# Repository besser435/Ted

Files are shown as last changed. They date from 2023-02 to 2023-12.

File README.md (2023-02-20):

# Ted
This is to store all of my Voron V0 3D printer stuff, including automated backups using the KIAUH gcode shell extention, and some other stuff like firmware and slicer profiles.
One important thing to note is that the autocommit script doesn't track deletions. 

To backup config files manually (run with `bash` NOT `sh`:
```
cd ~/Ted
bash autocommit.sh

```

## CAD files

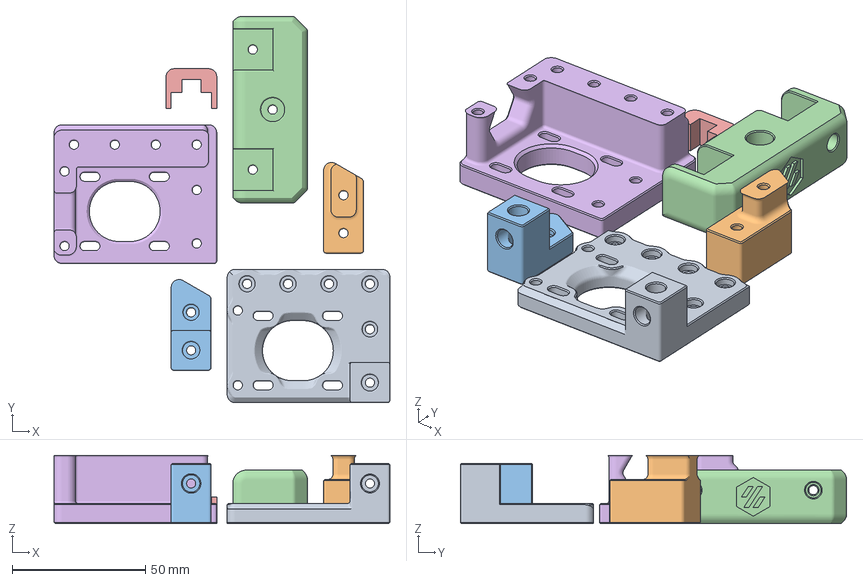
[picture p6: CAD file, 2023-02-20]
VORON Print Files/Main Parts/Batch 1 Main Parts/Batch 1 Main Parts.3mf
125.9 x 144.8 x 25.5 mm
B_Drive_Frame_Top_x1.STL
B_Idler_Bottom_x1.STL
B_Idler_Top_x1.STL
Front_Bed_Mount_x1.STL
MGN7_Rail_Guide_x2.STL
B_Drive_Frame_Bottom_x1.STL

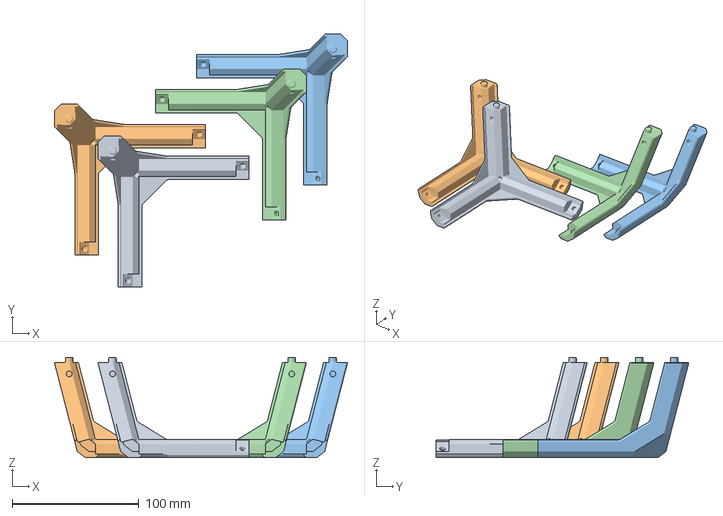
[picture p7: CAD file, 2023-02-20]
VORON Print Files/Tophat/Tophat Main Parts.3mf
231.1 x 199.1 x 79.0 mm
TopHat_Right_x2.STL
TopHat_Left_x2.stl

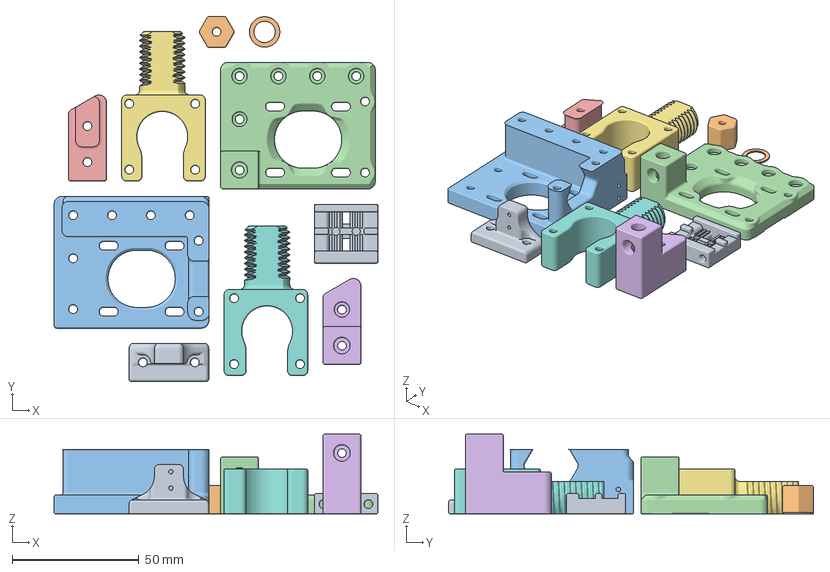
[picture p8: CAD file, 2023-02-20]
VORON Print Files/Main Parts/Batch 1 Main Parts/Accent Batch 1 Main Parts/Accent Batch 1 Main Parts.3mf
127.6 x 144.0 x 31.5 mm
[a]_Z_Endstop_Mount_x1.STL
[a]_Z_Leadscrew_Spacer_x1.stl
A_Drive_Frame_Bottom_x1.STL
A_Drive_Frame_Top_x1.STL
A_Idler_Bottom_x1.STL
A_Idler_Top_x1.STL
[a]_A_Drive_Tensioner_x1.STL
[a]_B_Drive_Tensioner_x1.STL
[a]_Belt_Retension_Block_x1.stl
[a]_Endstop_Strike_Block_x1.STL

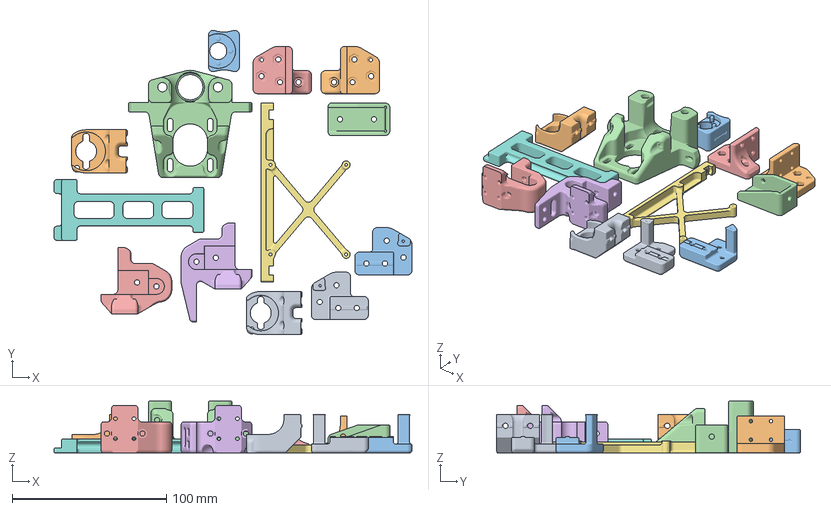
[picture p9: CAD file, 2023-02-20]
VORON Print Files/Main Parts/Batch 2 Main Parts/Batch 2 Main Parts.3mf
231.9 x 197.1 x 33.5 mm
XY_Joint_Left_Top_x1.STL
XY_Joint_Right_Bottom_x1.STL
XY_Joint_Right_Top_x1.STL
Z_Motor_Mount_x1.STL
Rear_Bed_Mount_Left_x1.STL
Rear_Bed_Mount_Right_x1.STL
RPi_Frame_x1.stl
Spool_Holder_V0_x1.STL
T8_Nut_Block_16mmx22mmOD_x1.STL
T8_Nut_Block_18mmx24mmOD_x1.STL
T-Nut_Mod_Tool_x1.STL
V0_Extrusion_Drilling_Guide_x1.STL
XY_Joint_Left_Bottom_x1.STL

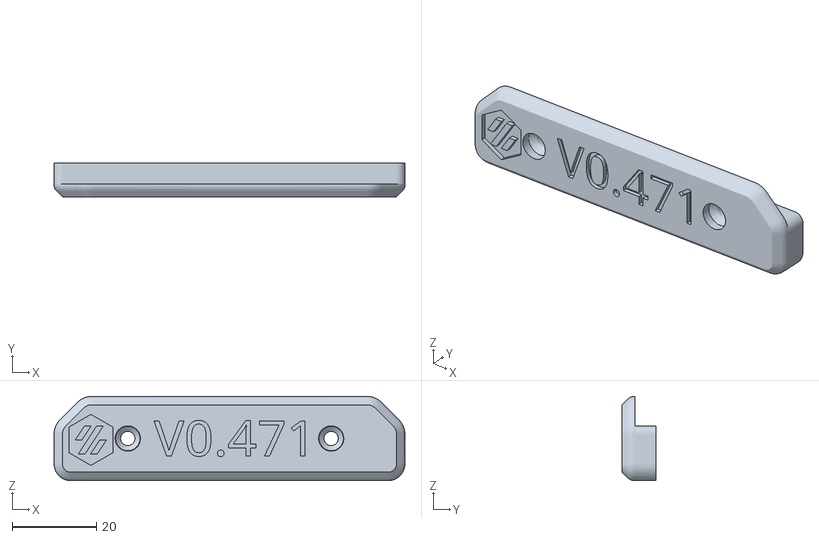
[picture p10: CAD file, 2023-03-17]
V0 SN.stl
83.2 x 8.00 x 20.0

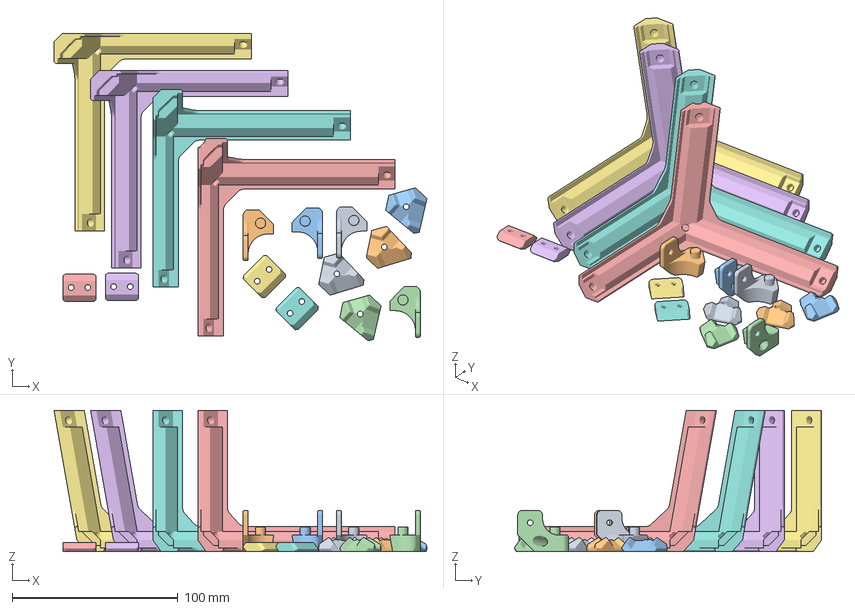
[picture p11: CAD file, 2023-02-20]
VORON Print Files/Bunged Up Files (Made for v0.1)/Enclosure (Contains Multiples)/(B) Entire Enclosure PLAquestionmark.3mf
224.8 x 185.1 x 85.0 mm
Lower_Corner_1_and_3_Clip_x2.stl
Lower_Corner_2_and_4_Clip_x2.STL
Tophat_Part1_x1.STL
Tophat_Part2_x2.STL
Tophat_Part3_x1.STL
Upper_Corner_1_and_3_Clip_x2.STL
Upper_Corner_2_and_4_Clip_x2.STL
Front_and_Rear_Midclip_x2.STL
Left_and_Right_Midclip_x2.STL

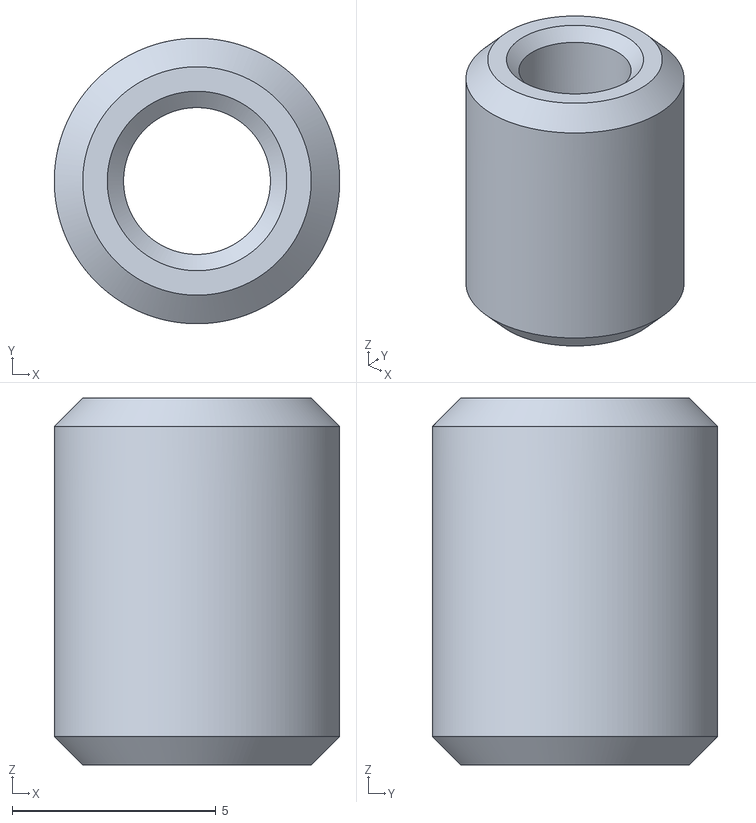
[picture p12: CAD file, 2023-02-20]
VORON Print Files/Bunged Up Files (Made for v0.1)/Mulitples of parts/[a]_9mm_Spacer_x6.stl
7.00 x 7.00 x 9.00

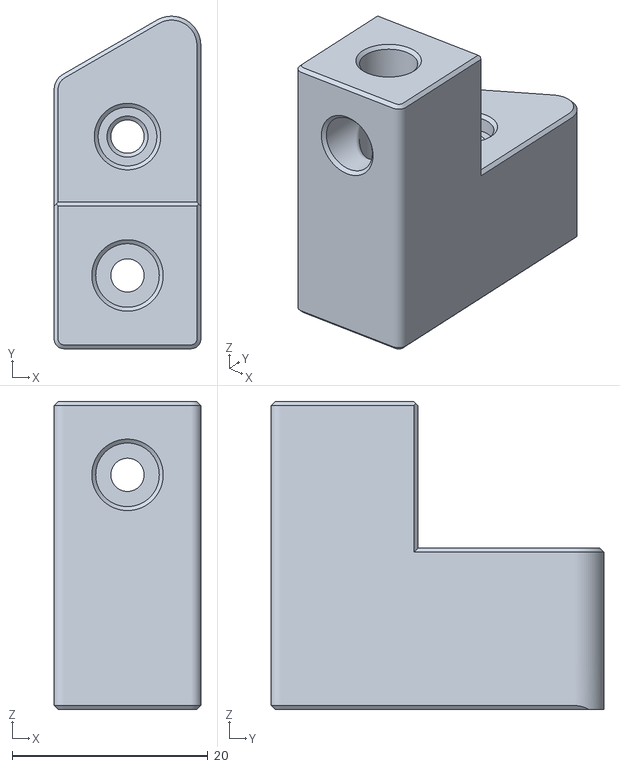
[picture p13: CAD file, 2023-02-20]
VORON Print Files/Bunged Up Files (Made for v0.1)/Regular Parts/Batch 1/Accent/A_Idler_Upper_x1.stl
15.0 x 34.0 x 31.5

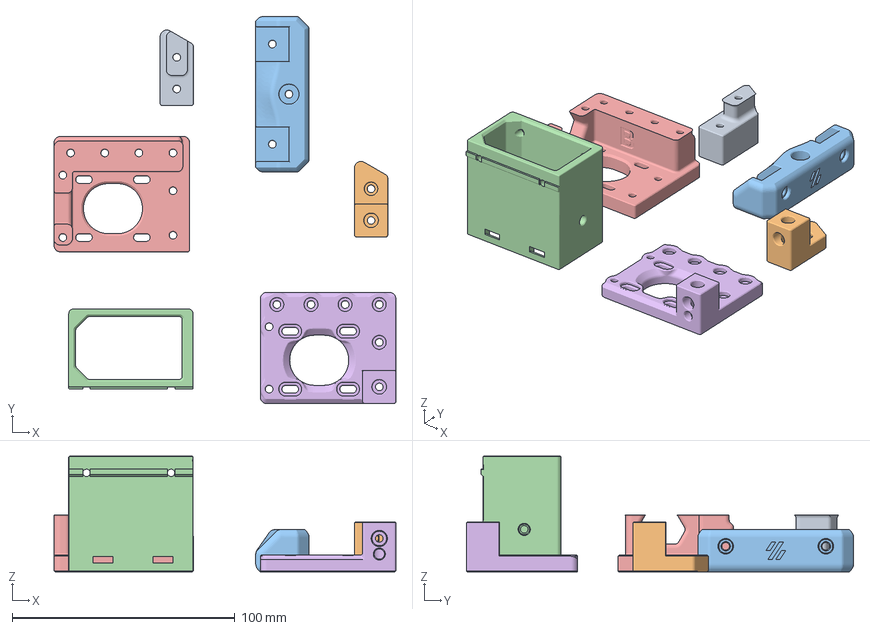
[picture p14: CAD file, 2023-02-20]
VORON Print Files/Bunged Up Files (Made for v0.1)/Regular Parts/Batch 1/B/(B) Batch 1.3mf
153.7 x 174.0 x 52.0 mm
B_Idler_Lower_x1.stl
B_Idler_Upper_x1.stl
Front_Bed_Mount_x1.stl
Power_Inlet_x1.stl
B_Drive_Frame_Lower_x1.stl
B_Drive_Frame_Upper_x1.stl

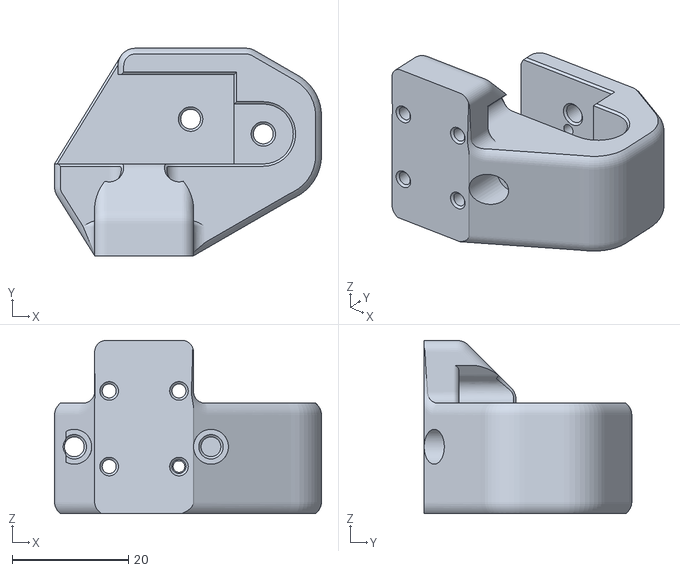
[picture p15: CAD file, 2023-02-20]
VORON Print Files/Bunged Up Files (Made for v0.1)/Regular Parts/Batch 2 (B)/Rear_Bed_Mount_Left_x1.stl
45.9 x 35.7 x 29.8

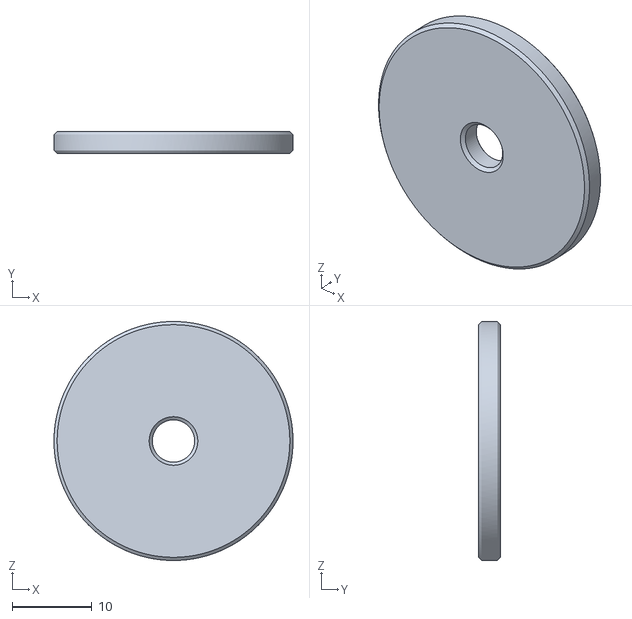
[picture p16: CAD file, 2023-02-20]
VORON Print Files/Bunged Up Files (Made for v0.1)/Tools/BMG_Shaft_Mod_Spacer_x1.STL
30.0 x 2.80 x 30.0

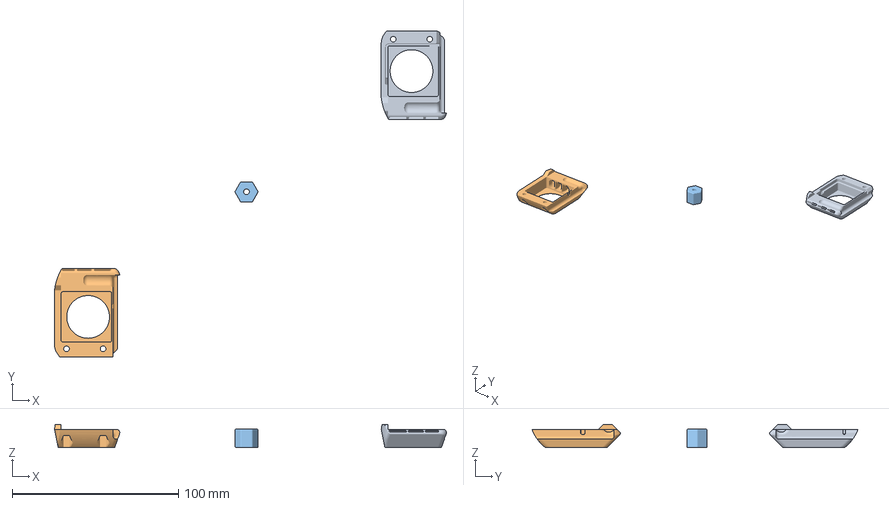
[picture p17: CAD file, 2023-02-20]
VORON Print Files/Bunged Up Files (Made for v0.1)/V6 Extruder/Accent/(A) Endstop block, fan ducts.3mf
235.8 x 196.3 x 14.1 mm
[a]_Toolhead_Blower_Duct_Left_TV6_x1.STL
[a]_Toolhead_Blower_Duct_Right_TV6_x1.STL
[a]_Endstop_Strike_Block_x1.STL

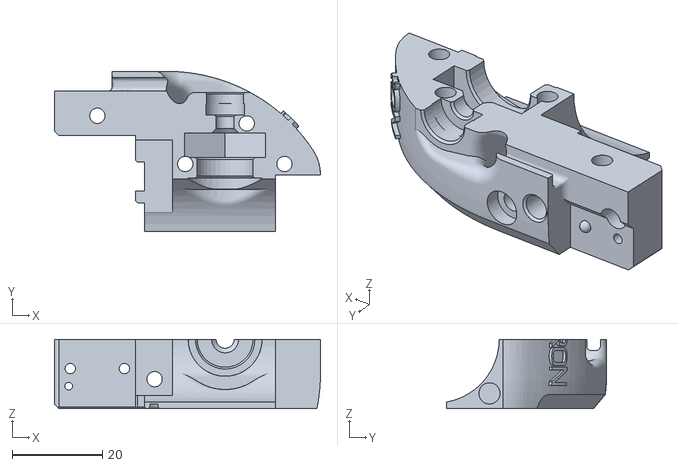
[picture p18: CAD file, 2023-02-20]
VORON Print Files/Bunged Up Files (Made for v0.1)/V6 Extruder/B/Toolhead_Right_Threaded_V6_x1.STL
59.0 x 35.6 x 15.4

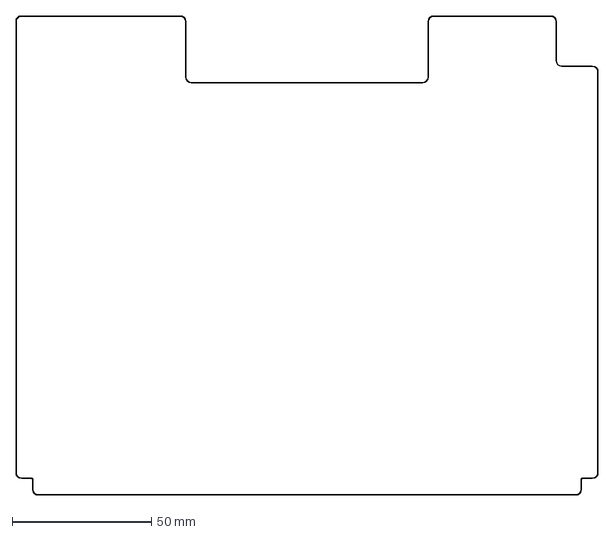
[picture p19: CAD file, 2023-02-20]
VORON Print Files/Bunged Up Files (Made for v0.1)/Voron-0-0.1/DXF/Deck_Panel_x1.DXF
209.0 x 172.0 mm

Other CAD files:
VORON Print Files/Bunged Up Files (Made for v0.1)/Voron-0-0.1/DXF/Tophat/Side_v0.1_x2.DXF
VORON Print Files/Bunged Up Files (Made for v0.1)/Voron-0-0.1/STLs/Panel_Mounting/Door_Latch_x2.STL
VORON Print Files/Bunged Up Files (Made for v0.1)/Voron-0-0.1/STLs/Panel_Mounting/For_2.5mm_Panels/2point5mm_Hinge_Bottom_B_x1.STL
VORON Print Files/Bunged Up Files (Made for v0.1)/Voron-0-0.1/STLs/Panel_Mounting/For_2mm_Panels/2mm_Bottom_Corner_Side_mirror_x1.STL
VORON Print Files/Bunged Up Files (Made for v0.1)/Enclosure (Contains Multiples)/Front_and_Rear_Midclip_x2.STL
VORON Print Files/Bunged Up Files (Made for v0.1)/Enclosure (Contains Multiples)/Left_and_Right_Midclip_x2.STL
VORON Print Files/Bunged Up Files (Made for v0.1)/Enclosure (Contains Multiples)/Lower_Corner_1_and_3_Clip_x2.stl
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

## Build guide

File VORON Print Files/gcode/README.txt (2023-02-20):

SLICE THE MOUNTING SUTFF, IT COMES IN DIFFERENT THICCNESSES

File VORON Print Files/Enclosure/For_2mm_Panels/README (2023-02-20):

STL's for panel mounting for 2mm thick exteriaor panels

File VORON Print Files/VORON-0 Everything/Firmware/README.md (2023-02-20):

## V0 Configuration Files:

# printer.cfg
***
- This is the base config that will need tweaking to your specific setup.

# bedScrewMenu.cfg
***
- This is an add-on to the main config that contains the code needed to  add the Bed Screw calibration menu options to the printers screen.
This routine moves your nozzle over top of the 3 bed screws on the V0 and allows you to manually adjust them to flatten the bed to the z-position of your endstop.
If you want to use this add-on config, place the `bedScrewMenu.cfg` file into the same location as your `printer.cfg` and add `[include bedScrewMenu.cfg]` to the bottom of the config.

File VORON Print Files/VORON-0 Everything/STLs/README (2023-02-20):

STL's for RC1 release of VORON Zero

Files that are Prefixed with [a]_ are intended to be printed in the accent color all other files are intended to be printed in the base color

toolhead folders contain all the parts that need to be printed for each specific toolhead, print the parts that match the hotend you are using.

Panel mounting clips are offered in 3 sizes. print the sizes that matches the thickness of the panels you are using.

The TopHat is available in a unibody one piece design as well as a 4 piece design (for printing directly on the V0) choose one or the other, 
you do not need both. the mounting brackets for tophat panels are also offered in 3 sizes. print the sizes that matches the thickness of the panels you are using.

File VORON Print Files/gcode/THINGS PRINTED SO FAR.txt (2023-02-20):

Batch 1 main parts, 9 hours 30 minutes
Batch 2 main parts, 14 hours 20 minutes
Mulitple parts, 11 hours 41 minutes
Tophat parts main parts, 10 hours 38 minutes
Toolhead, 2 hours 48 minutes
Extruder, 4 hours 30 minutes

Accent toolhead, 1 hour 45 minutes
Accent multiple parts,
Accent main parts, 9 hours 45 minutes

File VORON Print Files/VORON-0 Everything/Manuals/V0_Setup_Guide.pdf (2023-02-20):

# Voron Design SKR Mini E3 Setup Guide

V0.0

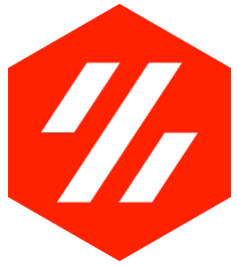
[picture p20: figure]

# Power Supply Wiring

## Safety Note

When wiring up your printer electronics, you will be working with high voltage wiring. Always double check to make sure that the printer is unplugged and any capacitors in your power supplies have discharged before touching any wire or terminal that may be live.

## Damage Risk

Never plug or unplug any device (high or low voltage) while the the printer is powered. In addition to being a safety hazard, you will likely damage electronic components. Of particular note are stepper drivers which can easily be damaged by connecting or disconnecting stepper motors or drivers while powered.

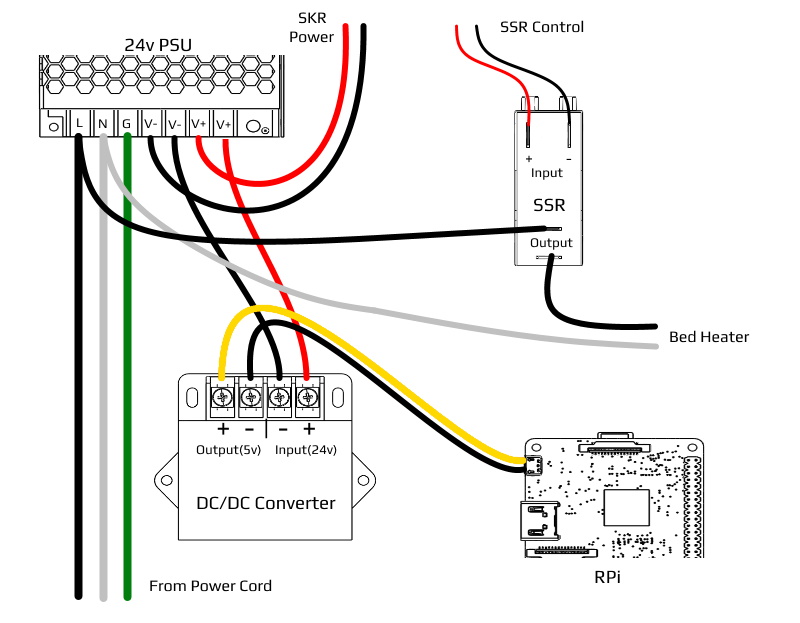
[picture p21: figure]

# SKR E3 Board Configuration

## Jumper Configuration

- Make sure power jumper is between INT and +5V (should be default from factory). If this is not installed correctly you may have power issues with your Raspberry Pi which can cause throttling

## Wire Terminals

SKR E3 boards use JST-XH terminals. This will mean that you will need to purchase a JST-XH connector kit with 2 pin, 3 pin, and 4 pin connectors. JST-XH terminals are keyed and will only fit in one orientation so pay close attention while crimping to make sure you do not make a mistake. You can carefully de-pin connectors with a dental pick, toothpick, or similar.

For wiring the stepper motors, keep the same wire color sequence that your stepper motors came with and make sure you use the same sequence for all of your stepper motors. If you have the spec motors from StepperOnline, the wires should in the the color order shown in the SKR E3 wiring diagrams on the following pages.

Note: Steppers should ship with a diagram that outlines wire pairs. You can also determine pairs by touching two wires together. If the stepper becomes more difficult to turn, then you have found a pair. These methods can be used if your wire colors are different or you mislabel wire order.

Important: If you find out your motors are going the wrong way once you start up your printer for the first time, you do not need to repin your connectors. You can invert the DIR (direction) pins in your configuration by adding or removing ! in front of pin and it will work properly.

## Endstop Wiring

There are two ways of wiring your endstops, one is NC (normally closed) and the other is NO (normally open). For normally closed configurations, the endstop switch allows current to flow through it when it is not triggered. For normally open configurations, the end stop switch only allows current to flow through it when it is triggered.

While both of these configurations will work fine in an ideal world, NC configurations are more robust because if a wire breaks or a terminal becomes disconnected, the printer will think that the end stop has triggered and the printer will stop movement before the toolhead crashes in to the frame or the bed.

Wiring mechanical end stop switches for NC operation is easy, as they generally have three pins exposed. With a multimeter, probe each combination of the three pins until you find a pair that has continuity (0 ohm resistance) when the switch is not triggered,

## MCU Wiring (X, Y, E, Hot End)

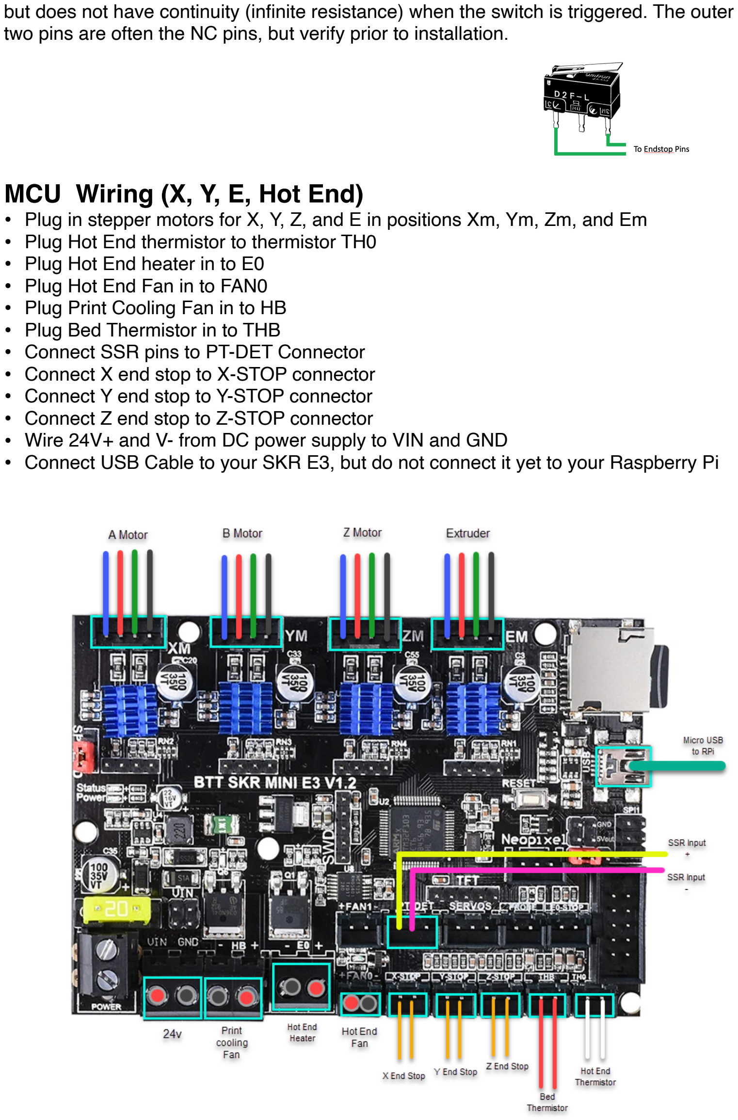
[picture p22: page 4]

but does not have continuity (infinite resistance) when the switch is triggered. The outer two pins are often the NC pins, but verify prior to installation.

- Plug in stepper motors for X, Y, Z, and E in positions Xm, Ym, Zm, and Em
- Plug Hot End thermistor to thermistor TH0
- Plug Hot End heater in to E0
- Plug Hot End Fan in to FAN0
- Plug Print Cooling Fan in to HB
- Plug Bed Thermistor in to THB
- Connect SSR pins to PT-DET Connector
- Connect X end stop to X-STOP connector
- Connect Y end stop to Y-STOP connector
- Connect Z end stop to Z-STOP connector
- Wire 24V+ and V- from DC power supply to VIN and GND
- Connect USB Cable to your SKR E3, but do not connect it yet to your Raspberry Pi

# Klipper Installation

References: Klipper Installation Instructions SKR Installation Instructions

## Installing Klipper Firmware on your SKR Mini E3 Board

- Install OctoPi on your Raspberry Pi (guide here: https://octoprint.org/download/)
- Once it is installed, ssh in to your Raspberry Pi using PuTTY on Windows or the Terminal on macOS

ssh pi@octopi OR ssh pi@192.168.1.X (Or whatever ip address your Raspberry Pi has)

- Enter password, the default one is “raspberry”. It is recommended to change this for security using
sudo raspi-config
Change the password via “Change User Password”
- Once you are at the command line of the Raspberry Pi, run the following commands: git clone https://github.com/KevinOConnor/klipper./klipper/scripts/install-octopi.sh
- When the install script has completed, run the following commands:
cd ~/klipper/
make menuconfig

In this menu structure, you’ll want to pick a few things. Make sure your Micro-controller Architecture is STM32, and your processor model is the STM32F103 with a 28KiB bootloader. Also select "enable extra low-level configuration options" and configure "GPIO pins to set at micro-controller startup" to "!PC13".
When your configuration matches the image below, select Exit and “Yes” if you are asked to save the configuration.

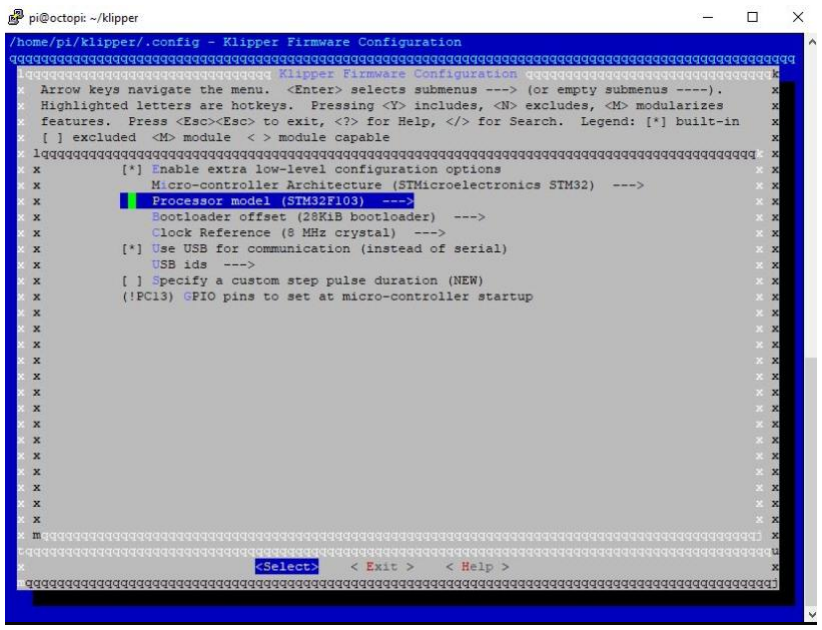
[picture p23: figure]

In the terminal window, type the following and pressing enter after each:

make clean

make

This command creates a firmware file klipper.bin that is stored in the folder /home/pi/ klipper/out.
The file needs to be copied to your Mini E3 board. The easiest way to do this is to use a program like WinSCP (Windows) or Cyberduck (Mac) to copy the file to your computer via SFTP. See the image on the next page that shows SFTP via Cyberduck.
- Copy the klipper.bin file to your desktop, and rename the file firmware.bin

Make sure the SKR Mini E3 is not powered, and then remove the microSD card.

- Connect the microSD card to your computer and open it.

There will be a file named firmware.cur on it—you can delete that file or keep it there, it does not matter.

- Copy the firmware.bin file from your desktop to the microSD card. If you have trouble transferring files from your computer to the microSD card, reformat the microSD card with a FAT32 file system and then try again.
- Plug the microSD cards back in to your SKR E3 board
- Turn on your power supply to power up your SKR E3 boards

Important: If you do not power your SKR with 12-24V, Klipper will be unable to communicate with the TMC drivers via UART and it will automatically shut down.

## Configuring Octoprint to use Klipper

Reference: KevinOConnor - klipper/docs/Installation.md
The OctoPrint web server needs to be configured to communicate with the Klipper host software.

Using a web browser, login to the OctoPrint web page and then configure the following items:

- Navigate to the Settings tab (the wrench icon at the top of the page)
- Under "Serial Connection" in "Additional serial ports" add "/tmp/printer" then click "Save"
- Open Settings tab and under "Serial Connection" change the "Serial Port" setting to "/ tmp/printer"
- In the Settings tab, navigate to the "Behavior" sub-tab and select the "Cancel any ongoing prints but stay connected to the printer" option, then click “Save”
- From the main page, under the "Connection" section (at the top left of the page) make sure the "Serial Port" is set to "/tmp/printer" and click "Connect". (If "/tmp/ printer" is not an available selection then try reloading the page)
- Once connected, navigate to the "Terminal" tab and type "status" (without the quotes) into the command entry box and click "Send". The terminal window will likely report there is an error opening the config file - that means OctoPrint is successfully communicating with Klipper.

## Setting up Voron Printer Configuration File

- Download the Voron Zero configuration file from the VORON 0 Github
- Transfer the downloaded file to your raspberry pi in the following folder: ~/home/pi

Note: There are many ways of editing your config file. Using the built-in Nano editor through SSH is simple, but it is not user friendly. Notepad++ with the NppFTP plugin (Windows) or bbEdit (MacOS) are better alternatives. Instructions on how to use them are in the appendix.

- Review the configuration file by typing:
nano ~/printer.cfg

You’ll notice that near the top of the file, there is a section titled [mcu] this section is where we define that we will be using the SKR E3 controller, and identifying the controller so that Klipper knows that components are connected to it. First of all, we need to identify what the Raspberry Pi calls the controller so we can correctly list it in the configuration.

- Take the USB cable from the SKR E3 and plug this in to one of the USB ports on your Raspberry Pi, then run the following command:
ls -l /dev/serial/by-id/

You should see something similar to this:

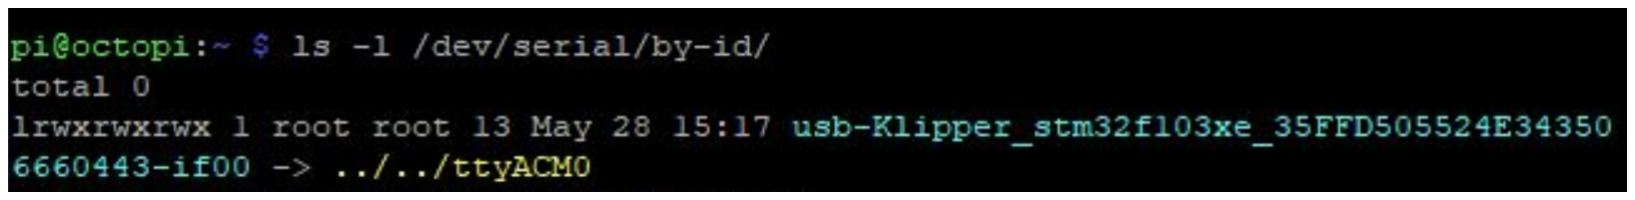
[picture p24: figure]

- Copy the corresponding text from your terminal window usb-Klipper_stm32f103xe_35FFD3054E4B323825611343-if00 and paste it in a text file temporarily.
- Open your configuration file (nano ~/printer.cfg) and navigate to the [mcu] section. After the text “serial: /dev/serial/by-id/” paste your SKR path so that the line becomes:

serial: /dev/serial/by-id/usb-Klipper_stm32f103xe_35FFD3054E4B323825611343-if00

- this wont be the exact line, your ID number will be different but the formate should be similar
- Exit the text editor using CNTL-X, and save when asked.
- Under Octoprint’s Terminal tab type:
FIRMWARE_RESTART and press enter send the command to restart Klipper.

NOTE: Pay close attention and complete the remaining configuration checks. If you do not complete these steps, your printer will not run!
1. Under [extruder] verify that your sensor_type is correct. Do not worry about step_distance and pid values for now, they will be updated later in the setup process.
2. Under [heater_bed], verify that your sensor type is correct.

Save the configuration file.

- Under Octoprint’s Terminal tab type:
FIRMWARE_RESTART and press enter send the command to restart Klipper.

The terminal window should show a status “Ready”—if not, type “status” in to the terminal command and press enter. If Klipper says that it is not ready, it will generally notify you if there is a configuration issue that needs to be fixed.

## Common Klipper Errors

TMC UART Error: This appears when the communication between the TMC drivers and the SKR is not working. Typically this means that you have not powered the SKR board with 12-24V (TMC drivers didn’t boot), you haven’t plugged in the TMC steppers to the correct spots, or you forgot to add or remove a jumper as detailed above.

ADC Error: ADC stands for “Analog to Digital Converter” and is what is used to convert thermistor readings to temperatures for your hotend and heated bed. As a safety precaution, if Klipper is expecting a thermistor to be plugged in but it is reading an invalid reading (no thermistor = open, or 0 ohms for a shorted wire as closed), it will go in to this shut down mode.

Unable to connect: Once the underlying issue is corrected, use the "FIRMWARE_RESTART" command to reset the firmware, reload the config, and restart the host software.
Check MCU IDs match your printer.cfg
"Make sure you get the paths right”

## Klipper Troubleshooting

Retrieve Log File: The Klippy log file (/tmp/klippy.log) contains debugging information. M112 command in the OctoPrint terminal window immediately after the undesirable event

There is a logextract.py script that may be useful when analyzing a micro-controller shutdown or similar problem.
mkdir work_directory

cd work_directory
cp /tmp/klippy.log .
~/klipper/scripts/logextract.py ./klippy.log
The script will extract the printer config file and MCU shutdown information to work_directory.

# Klipper Configuration Checks

The moment you’ve been waiting for—your printer finally coming to life! Klipper has a very helpful configuration check guide that will help make sure that everything is operating properly. Please follow the steps detailed at the URL below:

https://github.com/KevinOConnor/klipper/blob/master/docs/Config_checks.md

## Endstop Check

Make sure that none of the X, Y, or Z Endstops are being pressed, and then send a QUERY_ENDSTOPS command via the Octoprint command line. The terminal window should respond with the following:

Send: QUERY_ENDSTOPS
Recv: x:open y:open z:open

If any of them say “triggered” instead of “open”, double check to make sure none of them are pressed. Next, manually press the X endstop, send the QUERY_ENDSTOPS command again, and make sure that the X endstop says “triggered” and the Y and Z endstops stay open. Repeat with the Y and Z endstops.

You may find that one of your Endstops has inverted logic (it displays “open” when it is pressed, and “triggered” when it is not). In this case, go to your printer’s config file and add or remove the ! In front of the pin. For instance, if your X endstop was inverted, you would add a ! In front of your pin number as follows:

endstop_pin: P1.28 —> !P1.28

## Stepper Motor Check

To verify that each stepper motor is operating correctly, send the following command: STEPPER_BUZZ STEPPER=stepper_x
Run this again for each of the motors (stepper_y, stepper_z, extruder). the Z motor should go UP first then down by 1mm each direction. If the stepper motors do not move, check wiring for loose connectors. if the steppers move the wrong direction flip the connector on your board.

## XY Homing Check

It’s time to start by homing X and Y! You’ll want to be able to quickly stop your printer in case something goes wrong (ie, the tool head goes in the wrong direction). There are a few ways of doing this—one is to use the E-stop button on your display (if you have one installed). Test the button and see what happens—Klipper should shut down, but the Raspberry Pi and Octoprint will still be running, but disconnected from Klipper. Press “Connect” in the upper left corner of Klipper, and then in the Octoprint terminal window send a FIRMWARE_RESTART command to get your printer back up and running.

The alternative to this is to have your laptop right next to the printer with “restart” already in the terminal command line in Octoprint. When you start homing your printer, if it goes in the wrong direction—quickly send the restart command and it will stop the printer.

The final option is to power off the entire printer if something goes wrong.

Now that you know how to stop the printer if something goes wrong, send a G28 X Y command to your printer. This will only home X and Y, not Z. The tool head should move to the right until it hits the X endstop, and then move to the back of the printer until it hits the Y endstop. In a CoreXY configuration, each motor has to move in order to get the toolhead to go in only an X or Y direction (think of an Etch a Sketch).

If the toolhead does not go in the correct direction, refer to the table below to figure out how to correct it. If you need to invert one of the motors, invert the direction pin (put a ! before the pin). If the motors are going in the directions that match the lower row, swap your X and Y connectors.

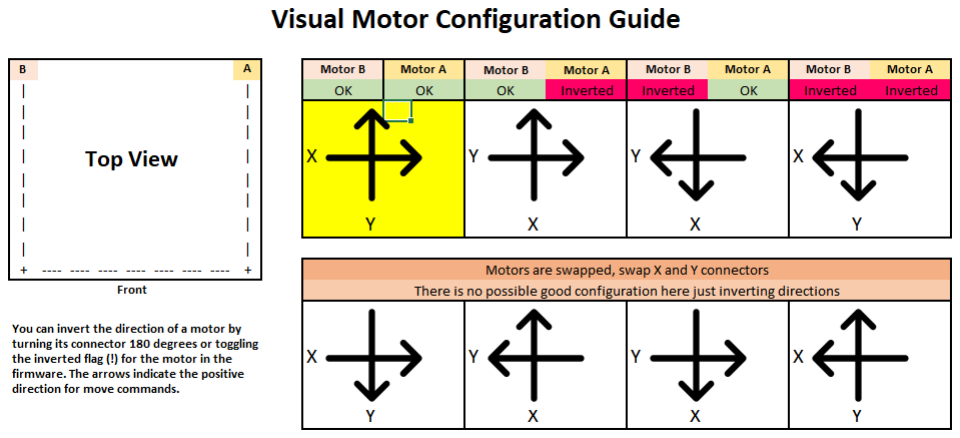
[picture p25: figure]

[stepper x] => Motor B
[stepper y] => Motor A

## Define (0,0) Point

Home XY
Move the nozzle to the front left corner of the bed. Once you can get the nozzle close to the front left corner of the bed, send an M114 command. If X and Y are not ~0-5mm, update “position_max” and “position_endstop” for both [stepper_x] and [stepper_y]: For X: New = Current – Get Position X Result

For Y: New = Current – Get Position Y Result
If you update anything in your configuration file, save the file and then restart Klipper using FIRMWARE_RESTART.

## PID Tune Heated Bed

Move nozzle to the center of the bed and approximately 5-10mm above the bed surface, then run:

PID_CALIBRATE HEATER=heater_bed TARGET=100

It will perform a PID calibration routine that will last about 10 minutes. Once it is finished, type SAVE_CONFIG which will save the parameters into your configuration file.

## PID Tune Hotend

Set the part cooling fans to 25% (M106 S64) and then run:

PID_CALIBRATE HEATER=extruder TARGET=245

It will perform a PID calibration routine that will last about 5 minutes. Once it is finished, type SAVE_CONFIG which will save the parameters into your configuration file.

## Z Offset Adjustment

If you did not run PID tuning, set your extruder to 245C and heated bed to 100C and let the printer heat up for 15 minutes.

Run a G28, and then move the nozzle to the center of the bed

Run Z_ENDSTOP_CALIBRATE

Slowly move the nozzle toward the bed by using
TESTZ Z=-1
Until the nozzle is relatively close to the bed, and then stepping down with
TESTZ Z=-0.1
Until the nozzle touches a piece of paper on top of the build plate. If you go far down, you can move the nozzle back up with:
TESTZ Z=0.1
Once you are satisfied with the nozzle height, type “ACCEPT” and then
“SAVE_CONFIG”.

If you get an error (out of bounds), send Z_ENDSTOP_CALIBRATE, ACCEPT, and then SAVE_CONFIG. This will redefine the 0 bed height so you will be able to get closer.

you will need to re-run these Z offset adjustment steps after the completion of the bed leveling section as well.

## Bed Leveling

The V0 uses manual bed leveling, the bed is small enough and thick enough that a mesh or other types of per print leveling are not needed. there is a Macro in Klipper to help with the manual bed leveling process

BED_SCREWS_ADJUST

This tool will move the printer's nozzle to each screw XY location and then move the nozzle to a Z=0.3 height. At this point one can use the "paper test" to adjust the bed screw directly under the nozzle. See the information described in "the paper test", but adjust the bed screw instead of commanding the nozzle to different heights. Adjust the bed screw until there is a small amount of friction when pushing the paper back and forth. this process will move all three mounting points of your bed closer to the nozzle so it is critical that you re-run the Z offset adjust after completing this section.

Once the screw is adjusted so that a small amount of friction is felt, run either the ACCEPT or ADJUSTED command. Use the ADJUSTED command if the bed screw needed an adjustment (typically anything more than about 1/8th of a turn of the screw). Use the ACCEPT command if no significant adjustment is necessary. Both commands will cause the tool to proceed to the next screw. (When an ADJUSTED command is used, the tool will schedule an additional cycle of bed screw adjustments; the tool completes successfully when all bed screws are verified to not require any significant adjustments.) One can use the ABORT command to exit the tool early.

After the BED_SCREWS_ADJUST command has been completed rerun the Z_ENDSTOP_CALIBRATE command to to bring your nozzle to the correct Z=0 position.

## Extruder Calibration

Before your first print, you need to make sure that your extruder extrudes the correct amount of material. With the hotend at temperature, make a mark between your roll of filament and your extruder, 120mm away from the entrance to your extruder. In Octoprint, extrude 50mm 2 times (for a total of 100mm—Klipper doesn’t allow you to extrude more than 50mm at a time), then measure from the entrance of your extruder to the mark you made previously. In a perfect world, it would measure 20mm (120mm -20mm = 100mm), but it usually won’t be. Take the value you have in your configuration file and update it using the following:

New Config Value = Old Config Value * (Actual Extruded Amount/Target Extruded Amount)

Note that a higher configuration value means that less filament is being extruded.

Paste the new value into your configuration file, restart Klipper, and try again. Once your extrusion amount is within 0.5% of the target value (ie, 99.5-100.5mm for a target 100mm of extruded filament), your extruder is calibrated!

## Fine Tuning Z Height

As a reference, if you adjust the Z offset during a print using the Tune menu on your display, you can update your printer configuration with this new value. Remember that higher values for your Z_endstop_position mean that the nozzle will be closer to the bed.

New Position = Old Position - Tune Adjustment
New Position = Old Position - (-0.050) = Old Position + 0.050

# Slicer Setup and First Print

## Cura Installation

For your first print, use the latest version of Cura, but do not open it at first. Download the latest Voron Cura setup files pinned in #slicers_and_print_help, and then extract the zip folder into C:\Program Files\Ultimaker Cura X.X\resources.

Once that is complete, open Cura and under “non-networked printer” find the Voron tab and select the size of your printer. All the settings should be pre-populated for you.

## First Print

Download the “voron_design_cube_v6.stl” from the Voron Github page (Voron-2/STLs/ TEST_PRINTS), and open the file in Cura. Use the default slicer settings, but make sure the hotend temperature and bed temperature is correct for the filament you are using. A good starting point is 240C hotend temperature, 100C heated bed temperature, and 92% flow for ABS.

Slice the file and save the .gcode file to your desktop (if you haven’t set up the Octoprint Plugin). Navigate to Octoprint in your web browser, and upload the file to Octoprint. Press “Print” and closely watch the beginning of the print. If your nozzle is too far or close to the bed, on your printer display press the knob, navigate to “Tune”, and adjust the Z offset distance (+ is further from the bed, - is closer).

Once you are printing (with your printer fully assembled), take a quick video, upload it to the Voron subreddit and eat a well deserved bowl of cereal!

# Appendix

## Appendix 1 - Notepad++ Configuration Editing (Windows)

1. Install Notepad++ from: https://notepad-plus-plus.org
2. Under the “Plugins” tab, select “Plugins Admin”
3. Search for “NppFTP”, select the check box, and click “Install”
4. Restart Notepad++ if necessary
5. On the right, there will be a new section. Click the gear icon and select “Profile Settings”
6. In the bottom left, select “Add New” and name the profile as you wish
7. In the Hostname dialog, enter the IP address of your Raspberry Pi
8. In Connection Type, select SFTP
9. Port: 22
10. Username: pi
11. Password: *** (default is raspberry)

12. Close the dialog box, select the blue symbol, and select the name of the profile you created
13. Notepad++ will connect to your Raspberry Pi and display the file structure
14. Navigate to /home/pi and open printer.cfg
15. Make any applicable edits and then save the file

Remember to restart klipper from the Octoprint terminal to see your changes take affect!

## Appendix 2 - bbEdit Configuration Editing (macOS)

1. Install bbEdit. The free version works great! https://www.barebones.com/products/bbedit/
2. Under File, select Open from FTP/SFTP Server…”
3. Under Server, type in your Raspberry Pi’s IP address (will be different)
4. Select SFTP
5. Enter “pi” as the user
6. Enter your password, it will be “raspberry” unless you changed it.
7. Select Continue
8. Find “printer.cfg” in the file browser and double click to open the file
9. Make any necessary edits and save the file

Remember to restart klipper from the Octoprint terminal to see your changes take affect!

## Appendix 3 - Recommended Octoprint Plugins

- OctoKlipper
- Themeify
- TerminalCommands
- Bed Level Visualizer
- Print Time Genius

## Appendix 5 - Other Accessories

To add LED lights inside the enclosure, wire up the (+) side of the LEDs to a power supply that matches the LED rated voltage, and the (-) side of the LEDs to one of the H-Bed (Heated Bed) connectors on either MCU. Define this output in your klipper configuration file and install an Octoprint plugin to control these LEDs.

## Appendix 6 - Contributors

- eddie V2.058
- nemgrea V2.199

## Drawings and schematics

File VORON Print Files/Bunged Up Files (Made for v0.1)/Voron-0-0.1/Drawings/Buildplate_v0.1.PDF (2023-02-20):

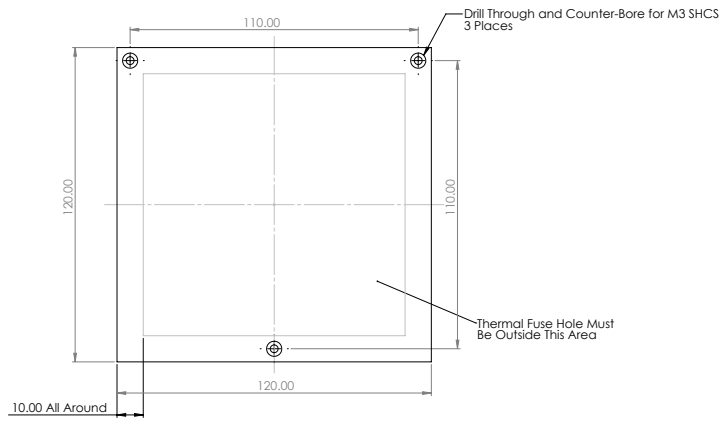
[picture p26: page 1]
10.00 All Around

Drill Through and Counter-Bore for M3 SHCS
3 Places

Thermal Fuse Hole Must
Be Outside This Area

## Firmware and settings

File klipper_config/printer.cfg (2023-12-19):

# This file contains common pin mappings for the BIGTREETECH SKR mini
# E3 v3.0. To use this config, the firmware should be compiled for the
# STM32G0B1 with a "8KiB bootloader" and USB communication.

# The "make flash" command does not work on the SKR mini E3. Instead,
# after running "make", copy the generated "out/klipper.bin" file to a
# file named "firmware.bin" on an SD card and then restart the SKR
# mini E3 with that SD card.

# See docs/Config_Reference.md for a description of parameters.
[virtual_sdcard]
path: ~/gcode_files
[display_status]
[pause_resume]
[include neopixel.cfg]
[exclude_object]


# Is SPI enabeld?: https://raspberrypi.stackexchange.com/questions/96670/find-out-whether-spi-is-enabled-or-not
# Enable SPI: https://www.mathworks.com/help/supportpkg/raspberrypiio/ref/enablespi.html
[mcu rpi]
serial: /tmp/klipper_host_mcu

[adxl345]
axes_map: x, z, y
cs_pin: rpi:None

[resonance_tester]
accel_chip: adxl345
probe_points:
    60, 60, 20  


[stepper_x]
step_pin: PB13
dir_pin: PB12	# Remove the ! if stepper is moving the opposite direction
enable_pin: !PB14
rotation_distance: 40
microsteps: 16
endstop_pin: !PC0 
position_endstop: 120
position_max: 120
homing_speed: 50   #Max 100
homing_retract_dist: 5
homing_positive_dir: true


[tmc2209 stepper_x]
uart_pin: PC11
tx_pin: PC10
uart_address: 0
run_current: 0.25
#hold_current: 0.0001   #not recommended according to the docs
stealthchop_threshold: 999999

[stepper_y]
step_pin: PB10
dir_pin: PB2	# Remove the ! if stepper is moving the opposite direction
enable_pin: !PB11
rotation_distance: 40
microsteps: 16
endstop_pin: !PC1
position_endstop: 120
position_max: 120
homing_speed: 50   #Max 100
homing_retract_dist: 5
homing_positive_dir: true

[tmc2209 stepper_y]
uart_pin: PC11
tx_pin: PC10
uart_address: 2
run_current: 0.25
#hold_current: 0.0001   #not recommended according to the docs
stealthchop_threshold: 999999


[stepper_z]
step_pin: PB0
dir_pin: PC5	# Remove the ! if stepper is moving the opposite direction
enable_pin: !PB1
rotation_distance: 8 #for T8x8 lead screw
#rotation_distance: 2 #for T8x2 lead screw
microsteps: 16
endstop_pin: !PC2
position_endstop: -.10
position_max: 115
position_min: -1
homing_speed: 10   #Max 100
second_homing_speed: 3.0
homing_retract_dist: 3.0


[tmc2209 stepper_z]
uart_pin: PC11
tx_pin: PC10
uart_address: 1
interpolate: False
run_current: 0.25
#hold_current: 0.0001   #not recommended according to the docs
sense_resistor: 0.110
stealthchop_threshold: 999999


[extruder]
step_pin: PB3
dir_pin: PB4
enable_pin: !PD1
microsteps: 16
rotation_distance: 22.68
gear_ratio: 50:17
nozzle_diameter: 0.400
filament_diameter: 1.750
heater_pin: PC8
sensor_type: EPCOS 100K B57560G104F
sensor_pin: PA0
control: pid
pid_Kp: 22.2
pid_Ki: 1.08
pid_Kd: 114
min_temp: 0
max_temp: 285
min_extrude_temp: 195
Pressure_advance: 0.18
pressure_advance_smooth_time: 0.040
max_extrude_only_distance: 500.0

[tmc2209 extruder]
uart_pin: PC11
tx_pin: PC10
uart_address: 3
run_current: 0.75
stealthchop_threshold: 999999

[heater_bed]
heater_pin: PC12
sensor_type: ATC Semitec 104GT-2
sensor_pin: PC4
control: pid
pid_kp: 58.437
pid_ki: 2.347
pid_kd: 363.769
min_temp: 0
max_temp: 115


[temperature_sensor raspberry_pi]
sensor_type: temperature_host
min_temp: 10
max_temp: 100


[temperature_sensor mcu_temp]
sensor_type: temperature_mcu
min_temp: 0
max_temp: 100



# physically swapped PC7 and PB15 to testing
[fan]   #Part cooling fan
pin: PC7


[heater_fan hotend_fan] 
pin: PB15
heater: extruder
heater_temp: 50.0
fan_speed: 0.6


[mcu] # can be obtained using KIAUH
serial: /dev/serial/by-id/usb-Klipper_stm32g0b1xx_3F003A001850344D30363620-if00


[printer]
kinematics: corexy
max_velocity: 500
max_accel: 10000
max_accel_to_decel: 10000
max_z_velocity: 35
max_z_accel: 350
square_corner_velocity: 5.0


[input_shaper]
shaper_freq_x: 102.2
shaper_type_x: ei
shaper_freq_y: 103.4
shaper_type_y: ei


[board_pins]
aliases:
    # EXP1 header
    EXP1_1=PB5,  EXP1_3=PA9,   EXP1_5=PA10, EXP1_7=PB8, EXP1_9=<GND>,
    EXP1_2=PA15, EXP1_4=<RST>, EXP1_6=PB9,  EXP1_8=PD6, EXP1_10=<5V>

# See the sample-lcd.cfg file for definitions of common LCD displays.


[idle_timeout]
timeout: 1800


[homing_override]
axes: z
set_position_z: 0
gcode:
   G90
   G0 Z5 F600
   G28 X Y
   G0 X30 Y0 F3600 
   
   G28 Z
   #G0 Z10 F1800
   #G0 X60 Y60 Z20 F3600
# Tool to help adjust bed leveling screws. One may define a
# [bed_screws] config section to enable a BED_SCREWS_ADJUST g-code
# command.


#[gcode_shell_command backup_cfg]
#command: bash /home/pi/Ted/autocommit.sh
#timeout: 40.
#verbose: True


[gcode_macro BACKUP_CFG]
gcode:
    SET_LED LED=neo RED=1 GREEN=0.549 BLUE=0
    RUN_SHELL_COMMAND CMD=backup_cfg
    SET_LED LED=neo RED=0 GREEN=0 BLUE=0 WHITE=1


[bed_screws]
screw1: 60,5
screw1_name: front screw
screw2: 5,115
screw2_name: back left
screw3: 115,115
screw3_name: back right


[gcode_macro PRINT_START]
#   Use PRINT_START for the slicer starting script - please customise for your slicer of choice
gcode:
    SET_LED LED=neo RED=0 GREEN=0 BLUE=1
    SET_LED LED=neo RED=1 GREEN=0 BLUE=1 INDEX=8
    SET_LED LED=neo RED=1 GREEN=0 BLUE=1 INDEX=10
    SET_LED LED=neo RED=1 GREEN=0 BLUE=1 INDEX=12
    SET_LED LED=neo RED=1 GREEN=0 BLUE=1 INDEX=14

    #G28                            ; home all axes
    G1 Z2 F1500                   ; move nozzle away from bed
   

[gcode_macro PRINT_END]
#   Use PRINT_END for the slicer ending script - please customise for your slicer of choice
gcode:
    SET_LED LED=neo RED=0.4862 GREEN=1 BLUE=0

    M400                           ; wait for buffer to clear
    G92 E0                         ; zero the extruder
    G1 E-3.0 F2000                 ; retract filament
    G91                            ; relative positioning

    #   Get Boundaries
    {% set max_x = printer.configfile.config["stepper_x"]["position_max"]|float %}
    {% set max_y = printer.configfile.config["stepper_y"]["position_max"]|float %}
    {% set max_z = printer.configfile.config["stepper_z"]["position_max"]|float %}

    #   Check end position to determine safe direction to move
    {% if printer.toolhead.position.x < (max_x - 20) %}
        {% set x_safe = 20.0 %}
    {% else %}
        {% set x_safe = -20.0 %}
    {% endif %}

    {% if printer.toolhead.position.y < (max_y - 20) %}
        {% set y_safe = 20.0 %}
    {% else %}
        {% set y_safe = -20.0 %}
    {% endif %}

    {% if printer.toolhead.position.z < (max_z - 2) %}
        {% set z_safe = 2.0 %}
    {% else %}
        {% set z_safe = max_z - printer.toolhead.position.z %}
    {% endif %}

    G0 Z{z_safe} F3600    ; move nozzle up
    G0 X{x_safe} Y{y_safe} F1800    ; move nozzle to remove stringing
    TURN_OFF_HEATERS
    M107                           ; turn off fan
    G90                            ; absolute positioning
    G0 X60 Y{max_y} F3600          ; park nozzle at rear
	

[gcode_macro LOAD_FILAMENT]
gcode:
   SET_LED LED=neo RED=1 GREEN=0.0784 BLUE=0.5764
   M83                            ; set extruder to relative
   G1 E380 F1800                  ; quickly load filament to down bowden
   G1 E35 F300                    ; slower extrusion for hotend path
   G1 E30 F140                    ; prime nozzle with filament
   M82                            ; set extruder to absolute
    

[gcode_macro UNLOAD_FILAMENT]
gcode:
   SET_LED LED=neo RED=1 GREEN=0.0784 BLUE=0.5764
   M83                            ; set extruder to relative
   G1 E10 F300                    ; extrude a little to soften tip
   G1 E-420 F2300                 ; retract filament completely
   M82                            ; set extruder to absolute


[gcode_macro PAUSE]
rename_existing: BASE_PAUSE
# change this if you need more or less extrusion
variable_extrude: 1.0
gcode:
  SET_LED LED=neo RED=1 GREEN=0.549 BLUE=0  # Orange
  ##### read E from pause macro #####
  {% set E = printer["gcode_macro PAUSE"].extrude|float %}
  ##### set park positon for x and y #####
  # default is your max posion from your printer.cfg
  {% set x_park = printer.toolhead.axis_maximum.x|float - 5.0 %}
  {% set y_park = printer.toolhead.axis_maximum.y|float - 5.0 %}
  ##### calculate save lift position #####
  {% set max_z = printer.toolhead.axis_maximum.z|float %}
  {% set act_z = printer.toolhead.position.z|float %}
  {% if act_z < (max_z - 2.0) %}
      {% set z_safe = 2.0 %}
  {% else %}
      {% set z_safe = max_z - act_z %}
  {% endif %}
  ##### end of definitions #####
  SAVE_GCODE_STATE NAME=PAUSE_state
  BASE_PAUSE
  G91
  G1 E-{E} F2100
  G1 Z{z_safe} F900
  G90
  G1 X{x_park} Y{y_park} F6000


[gcode_macro RESUME]
rename_existing: BASE_RESUME
gcode:
  SET_LED LED=neo RED=0 GREEN=0 BLUE=1
  ##### read E from pause macro #####
  {% set E = printer["gcode_macro PAUSE"].extrude|float %}
  ##### end of definitions #####
  G91
  G1 E{E} F1800
  RESTORE_GCODE_STATE NAME=PAUSE_state
  BASE_RESUME
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

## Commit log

2023-02-18 Autocommit from 2023-02-18 12:29:17
    Klipper on commit: 51da02b
    Moonraker on commit: dde9bcc
    Fluidd version: v1.23.1
2023-02-18 Autocommit from 2023-02-18 05:42:32
    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
2023-02-18 Autocommit from 2023-02-18 06:46:09
    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
    [fluidd.cfg, klipper.cfg, neopixel.cfg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]
2023-02-18 Autocommit from 2023-02-18 06:52:33
    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
2023-02-18 Autocommit from 2023-02-18 07:01:47
    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
    [fluidd.cfg, klipper.cfg, neopixel.cfg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]
2023-02-18 Autocommit from 2023-02-18 07:13:00
    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
2023-02-18 Autocommit from 2023-02-18 07:29:33
    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
    [printer.cfg]
2023-02-18 Autocommit from 2023-02-18 07:29:42
    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
2023-02-18 Autocommit from 2023-02-18 07:33:11
    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
    [printer.cfg]
2023-02-18 Autocommit from 2023-02-18 07:37:09
    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
2023-02-20 Create firmware (klipper v0.10.0-237-g28b568a6).bin
2023-02-20 Autocommit from 2023-02-19 20:10:14
    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
    [printer.cfg]
2023-02-20 Autocommit from 2023-02-19 20:32:08
    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
    [printer.cfg]
2023-02-20 Create bed model.stl
2023-03-17 Autocommit from 2023-03-17 07:10:52
    Klipper on commit: a5fb207
    Moonraker on commit: 80fb97c
    Fluidd version: v1.23.2
    [printer.cfg]
2023-03-17 Create V0 SN.stl
    [V0 SN.stl]
2023-04-01 Autocommit from 2023-04-01 06:43:23
    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
    [printer.cfg]
2023-04-22 Autocommit from 2023-04-22 11:58:46
    Klipper on commit: 011b4e3
    Moonraker on commit: eff0901
    Fluidd version: v1.23.5
    [printer.cfg]
2023-06-07 Autocommit from 2023-06-06 22:05:07
    Klipper on commit: 33b18fd
    Moonraker on commit: b21f177
    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
    [printer fast.cfg, printer.cfg]
2023-06-24 Autocommit from 2023-06-24 07:49:31
    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
    [printer.cfg]
2023-07-28 Autocommit from 2023-07-27 18:40:38
    Moonraker on commit: 937c766
    Fluidd version: v1.24.2
    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
2023-12-14 Autocommit from 2023-12-14 05:15:16
    Klipper on commit: 99d7af8
    Moonraker on commit: 9ad8fed
    Fluidd version: v1.26.3
    [printer.cfg]
2023-12-19 Autocommit from 2023-12-19 04:42:46
    Klipper on commit: 3417940
    Moonraker on commit: 4235789
    Fluidd version: v1.27.0
    [printer.cfg]
